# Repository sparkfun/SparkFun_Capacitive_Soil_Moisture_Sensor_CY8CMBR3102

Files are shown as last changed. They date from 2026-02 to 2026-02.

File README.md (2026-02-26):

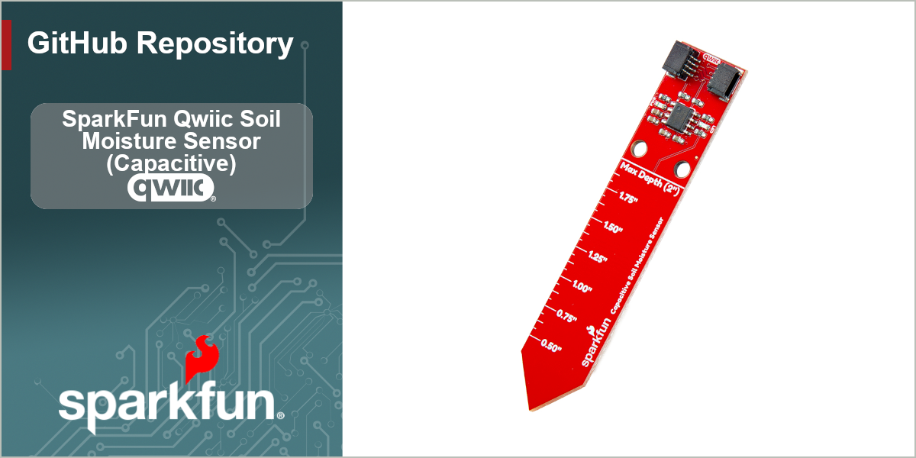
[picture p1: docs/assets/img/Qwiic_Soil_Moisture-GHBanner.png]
SparkFun Qwiic Soil Moisture Sensor (Capacitive) (https://www.sparkfun.com/sparkfun-qwiic-soil-moisture-sensor-capacitive.html)


[*SparkFun Qwiic Soil Moisture Sensor (Capacitive) (SEN-30480)*](https://www.sparkfun.com/sparkfun-qwiic-soil-moisture-sensor-capacitive.html)

The SparkFun Qwiic Soil Moisture Sensor (Capacative) is a simple sensor breakout to measure moisture in soil and similar substances. The breakout measures moisture using a capacitive plate in the board along with the CY8CMBR3102 Capsense<sup>&reg;</sup> Express<sup>&trade;</sup> controller. Because this soil moisture sensor does not have exposed metal leads it's more resistant to corrosion. The board also includes a ruler with both Imperial and Metric units to measure the sensor's depth in soil for more precise moisture data. There's also a blue status LED tied to the CY8CMBR3102 which can be used as a visual indicator for when the sensor measures beyond a user-defined threshold value.

The SparkFun Qwiic Soil Moisture Sensor (Capacative) has code packages available for both the Arduino IDE and MicroPython. These code packages cover how to calibrate the sensor for different soil compositions to get reliable and usable soil moisture data from the sensor.

Repository Contents
-------------------

* **/docs** - GitHub pages documentation files
* **/Documentation** - Datasheets, etc. 
* **/Hardware** - KiCad design files (_pcb, _sch), Schematic (PDF)
* **/Production** - Production panel files (_pcb, gerbers)

Documentation
--------------
* [**Arduino Library**](https://github.com/sparkfun/SparkFun_CY8CMBR3_Arduino_Library) - Arduino library for CY8CMBR3xxx capacitance sensors, specifically for the Qwiic Soil Moisture Sensor (Capacitive).
* [**Python Package**](https://github.com/sparkfun/qwiic_cy8cmbr3_py) - A Python driver for CY8CMBR3xxx capacitance sensors, specifically for the Qwiic Soil Moisture Sensor (Capacitive).
* [**Hookup Guide**](https://docs.sparkfun.com/SparkFun_Capacitive_Soil_Moisture_Sensor_CY8CMBR3102/introduction/) - A basic guide to get started with the Qwiic Soil Moisture Sensor (Capacitive)

Product Versions
-----------------

* [SEN-30480](https://www.sparkfun.com/sparkfun-qwiic-soil-moisture-sensor-capacitive.html) - Initial SparkFun Qwiic Soil Moisture Sensor (Capacitive) release.

License Information
-------------------

This product is _**open source**_! 

Please review the LICENSE.md file for license information. 

If you have any questions or concerns on licensing, please contact technical support on our [SparkFun forums](https://forum.sparkfun.com/viewforum.php?f=152).

Distributed as-is; no warranty is given.

- Your friends at SparkFun.

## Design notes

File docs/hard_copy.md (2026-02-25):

---
icon: material/book-open-variant
---

Need to download or print our hookup guide?

* [Print :fontawesome-solid-print:](../single_page.md) (Single-Page View)
    * To save as a `*.pdf` file, select the **Printer** or **Destination** labeled ++"Save as PDF"++. *(Instructions will vary based on the browser)*

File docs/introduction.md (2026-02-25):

<figure markdown>
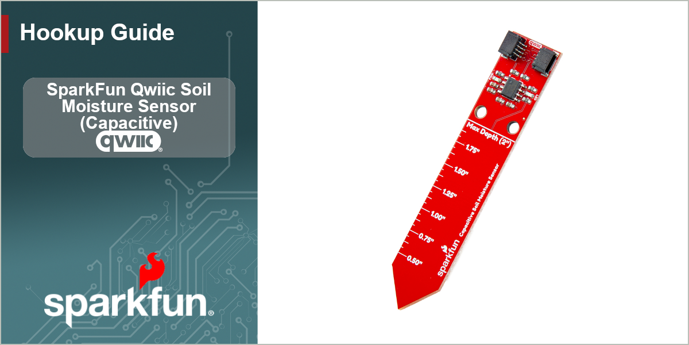
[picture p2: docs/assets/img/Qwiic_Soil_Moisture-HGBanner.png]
Banner Image (https://www.sparkfun.com/sparkfun-qwiic-soil-moisture-sensor-capacitive.html)

</figure>

The SparkFun Qwiic Soil Moisture Sensor (Capacative) is a simple sensor breakout to measure moisture in soil and similar substances. The breakout measures moisture using a capacitive plate in the board along with the CY8CMBR3102 Capsense<sup>&reg;</sup> Express<sup>&trade;</sup> controller. Because this soil moisture sensor does not have exposed metal leads it's more resistant to corrosion. The board also includes a ruler with both Imperial and Metric units to measure the sensor's depth in soil for more precise moisture data. There's also a blue status LED tied to the CY8CMBR3102 which can be used as a visual indicator for when the sensor measures beyond a user-defined threshold value.

The SparkFun Qwiic Soil Moisture Sensor (Capacative) has code packages available for both the Arduino IDE as well as MicroPython. These code packages cover how to calibrate the sensor for different soil compositions to get reliable and usable soil moisture data from the sensor.

In this Quick Start guide we'll cover how to assemble the sensor into a Qwiic circuit and use the SparkFun CY8CMBR3 Arduino Library to get capacitance data we can use to determine soil moisture.

## Required Materials

In order to use this Qwiic breakout board, you'll need the following materials:

* [SparkFun RedBoard IoT - ESP32](https://www.sparkfun.com/sparkfun-iot-redboard-esp32-development-board.html) (or other Arduino development board)
* [Qwiic Cable](https://www.sparkfun.com/flexible-qwiic-cable-100mm.html)

## Resources and Support Documentation

You'll find the board design files (KiCad files & schematic), relevant documentation (datasheets, white papers, etc.) and other helpful links in the **Resources**. Lastly, the **Support** section includes a Troubleshooting page that includes any helpful tips specific to this board as well as information on how to receive technical support from SparkFun.

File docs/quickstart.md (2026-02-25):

In this Quick Start guide we'll assemble the SparkFun Qwiic Soil Moisture Sensor (Capacitive) in a Qwiic circuit with the SparkFun RedBoard - IoT (ESP32) and then demonstrate how to calibrate the sensor and get soil moisture data from it using the SparkFun CY8CMBR3x Arduino Library. This guide assumes users have an understanding of the Qwiic ecosystems and how to use development boards with the Arduino IDE.

<figure markdown>
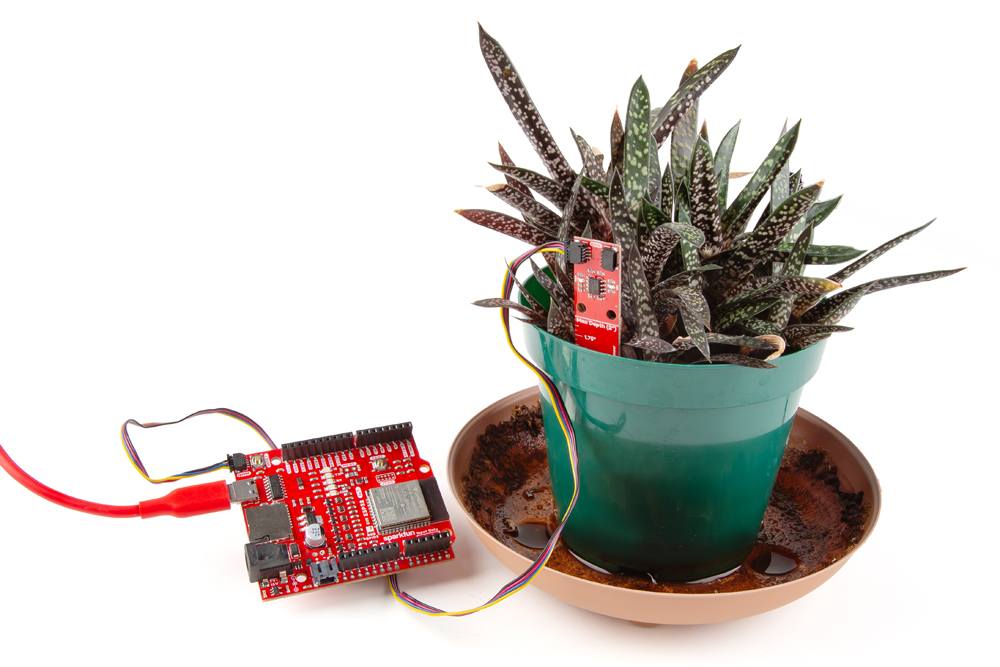
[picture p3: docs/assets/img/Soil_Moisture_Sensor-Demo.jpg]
Qwiic Soil Moisture Sensor demo image

</figure>

## Recommended Reading

If you've never worked with microcontrollers, Arduino (or Python/MicroPython), or the Qwiic ecosystem; take a look at the following resources:

* [SparkFun IoT RedBoard - ESP32 Hookup Guide](https://learn.sparkfun.com/tutorials/iot-redboard-esp32-development-board-hookup-guide)
* [Getting Started with Arduino IDE V2](https://docs.arduino.cc/software/ide-v2/tutorials/getting-started-ide-v2/)
* [Setup and Using MicroPython for Beginners](https://learn.sparkfun.com/tutorials/setup-and-using-micropython-for-beginners)
* [Qwiic Info Page](https://www.sparkfun.com/qwiic?)

## Qwiic Assembly

* Connect the Qwiic Soil Moisture Sensor to the RedBoard IoT using a Qwiic cable.
* Connect the RedBoard IoT to your computer over USB-C.

<figure markdown>
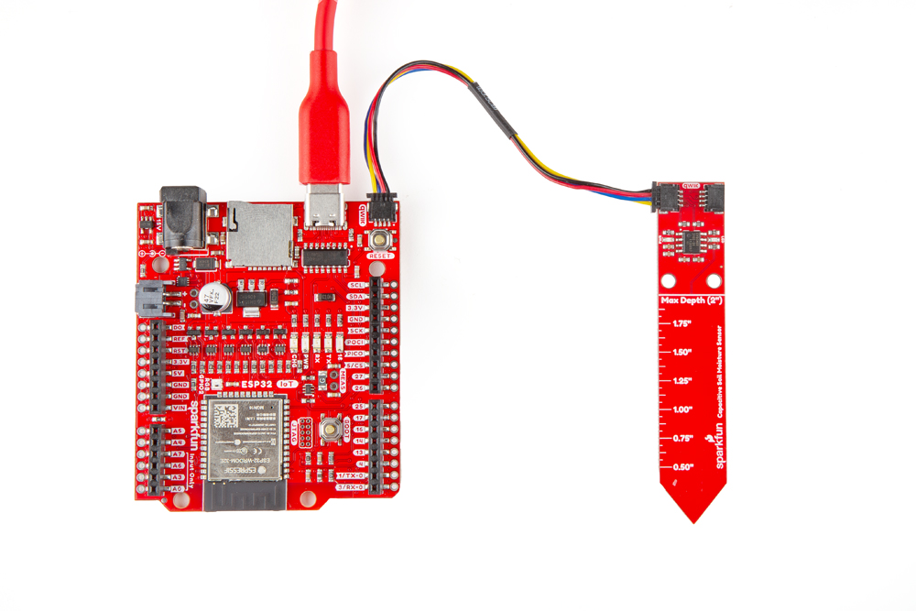
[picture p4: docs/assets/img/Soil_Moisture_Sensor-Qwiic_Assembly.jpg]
Completed Soil Moisture assembly with RedBoard IoT

</figure>

## Soil Moisture Example

Now that we've connected everything up we can move on to uploading example code to get data from the sensor. We'll be demonstrating the basic example included in the Arduino Library but if you're using the MicroPython package the basic example included with it will return the same data shown here. This example initializes the sensor with default settings and prints out the capacitance (in picofarads) returned by the sensor.

* Open the [Arduino IDE](https://docs.arduino.cc/software/ide-v2/tutorials/getting-started-ide-v2/).
* Open the [Library Manager](https://docs.arduino.cc/software/ide-v2/tutorials/ide-v2-installing-a-library/) tool, search for "SparkFun CY8CMBR3" and install the latest version. This library was built using the [SparkFun Toolkit](https://github.com/sparkfun/SparkFun_Toolkit) so if you have not already installed it, search for "SparkFun Toolkit" in the Library Manager to install the dependency. 
* Open **Example01 - Basic Usage**.
* Select your Board (SparkFun RedBoard IoT - ESP32 or other board) and Port and click the "Upload" button.
* After code finishes compiling and uploading, open the [serial monitor](https://docs.arduino.cc/software/ide-v2/tutorials/ide-v2-serial-monitor/) with the baud set to **115200**.

After the code initializes you should see capacitance values (in picofarads/pf) print out every 500ms. Try touching the sensing area or insert it into the soil you'll be measuring to see the values change.

### Sensor Calibration

The Qwiic Soil Moisture Sensor (Capacitive) operates by detecting changes in capacitance in the soil it's inserted into. This works in measuring soil moisture by measuring the soil's change in [relative permittivity (or dielectric constant)](https://en.wikipedia.org/wiki/Relative_permittivity). Put simply, wet soil has a higher relative permittivity than dry soil and therefore the sensor will report higher capacitance values in wet soil. As soil dries out, it loses permittivity and the measured capacitance drops. 

Different soil types and environments can return significantly different capacitance values so it is important to calibrate the Qwiic Soil Moisture Sensor (Capacitive) to get an effective range of values for the soil it's monitoring. Start by inserting the sensor into a *completely dry* soil sample to get the minimum values for the soil. Then place the sensor into a *completely saturated* sample of the same soil to get the max values. With this range defined, you can create thresholds to trigger events like turning on the Soil Moisture Sensor's blue STAT LED when a threshold is exceeded as demonstrated in Example 03 - LED.

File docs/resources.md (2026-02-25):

For more information about the SparkFun Qwiic Soil Moisture Sensor (Capacitive) check out the following resources:

* [Schematic](./assets/board_files/SparkFun_Qwiic_Soil_Moisture_Sensor_Capacitive.pdf)
* [KiCad Files](./assets/board_files/SparkFun_Qwiic_Soil_Moisture_Sensor_Capacitive.zip)
* [Board Dimensions](./assets/board_files/SparkFun_Qwiic_Soil_Moisture_Sensor_Capacitive.jpg)
* [Datasheet](./assets/component_documentation/infineon-cy8cmbr3002-cy8cmbr3102-cy8cmbr3106s-cy8cmbr3108-cy8cmbr3110-cy8cmbr3116-datasheet-en.pdf)
* [SparkFun CY8CMBR3 Arduino Library](https://github.com/sparkfun/SparkFun_CY8CMBR3_Arduino_Library)
* [SparkFun CY8CMBR3 Python Package](https://github.com/sparkfun/qwiic_cy8cmbr3_py)

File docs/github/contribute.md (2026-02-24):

# Contribute: Make an Augmentation!
Spot an improvement opportunity? Feel free to contribute to our open-source design and documentation. 

## :material-file-document-multiple:&nbsp;Improve our Documentation
All of this documentation can be modified by you! Please help us make it better.

* These pages are contained in the [`docs` folder](https://github.com/sparkfun/SparkFun_Capacitive_Soil_Moisture_Sensor_CY8CMBR3102/tree/main/docs) of the [SparkFun Qwiic Soil Moisture Sensor  (Capacitive) repository](https://github.com/sparkfun/SparkFun_Capacitive_Soil_Moisture_Sensor_CY8CMBR3102).

<!-- ### :material-source-pull:&nbsp;Submit a Correction -->
### Submit a Correction

1. With a GitHub account, [fork this repository](https://github.com/sparkfun/SparkFun_Capacitive_Soil_Moisture_Sensor_CY8CMBR3102/fork).
2. Add your corrections or improvements to the markdown file.
3. File a pull request with your changes, and enjoy making the ~~words~~ ~~worlds~~ world a better place.
	* Once received, the documentation specialist will automatically be notified.
	* We will review your suggested improvements to make sure they are correct and fit within our documentation standards.

## :material-cog:&nbsp;Improve our Hardware Design
All of our designs are open-source! Please help us make it better.

* Our board design files are contained in the [`Hardware` folder](https://github.com/sparkfun/SparkFun_Capacitive_Soil_Moisture_Sensor_CY8CMBR3102/tree/main/Hardware) of the [SparkFun Qwiic Soil Moisture Sensor  (Capacitive) repository](https://github.com/sparkfun/SparkFun_Capacitive_Soil_Moisture_Sensor_CY8CMBR3102).

<!-- ### :material-source-pull:&nbsp;Submit a Design Enhancement -->
### Submit a Design Enhancement

1. With a GitHub account, [fork this repository](https://github.com/sparkfun/SparkFun_Capacitive_Soil_Moisture_Sensor_CY8CMBR3102/fork).
2. Add your design augmentation(s)
3. File a pull request with your changes, and enjoy making the ~~words~~ ~~worlds~~ world a better place.
	1. Once received, the engineer in charge of the original design will automatically be notified.
	2. We will review your suggested improvement(s) to verify that they are within our board design standards and meet our product design requirements.
	3. If approved, we will flag these changes for our next board revision. Congrats! 🍻

		!!! info
			Even if your suggestion is accepted, these changes may not be immediately available for purchase. We may have to cycle through our current product inventory first.

## Contributors&nbsp;:clap:
Let's provide some recognition to the contributors for this project!

GitHub Contributors Image
<br>


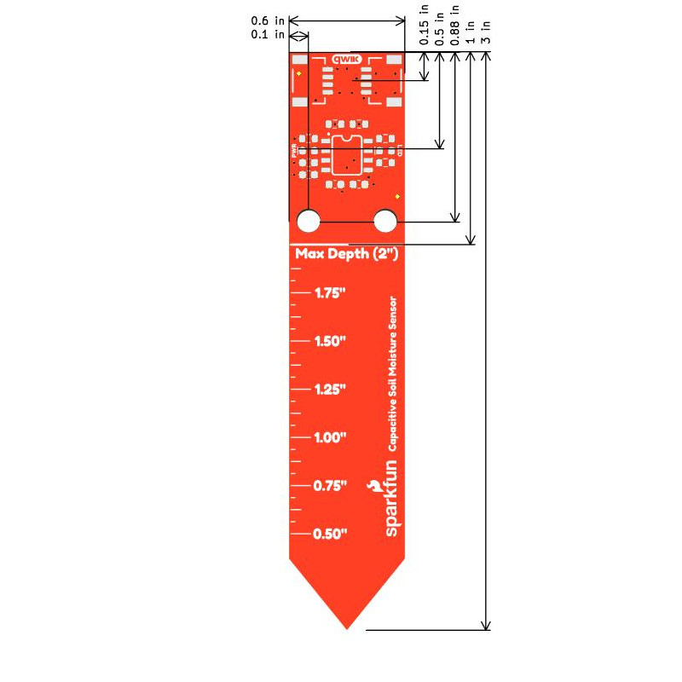
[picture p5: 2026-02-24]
docs/assets/board_files/SparkFun_Qwiic_Soil_Moisture_Sensor_Capacitive.jpg

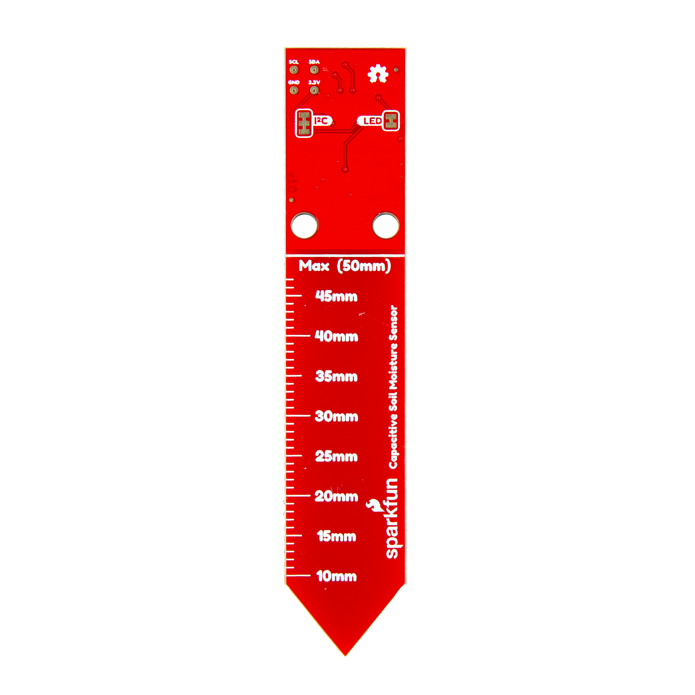
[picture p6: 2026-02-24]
docs/assets/img/Soil_Moisture_Sensor-Back.jpg

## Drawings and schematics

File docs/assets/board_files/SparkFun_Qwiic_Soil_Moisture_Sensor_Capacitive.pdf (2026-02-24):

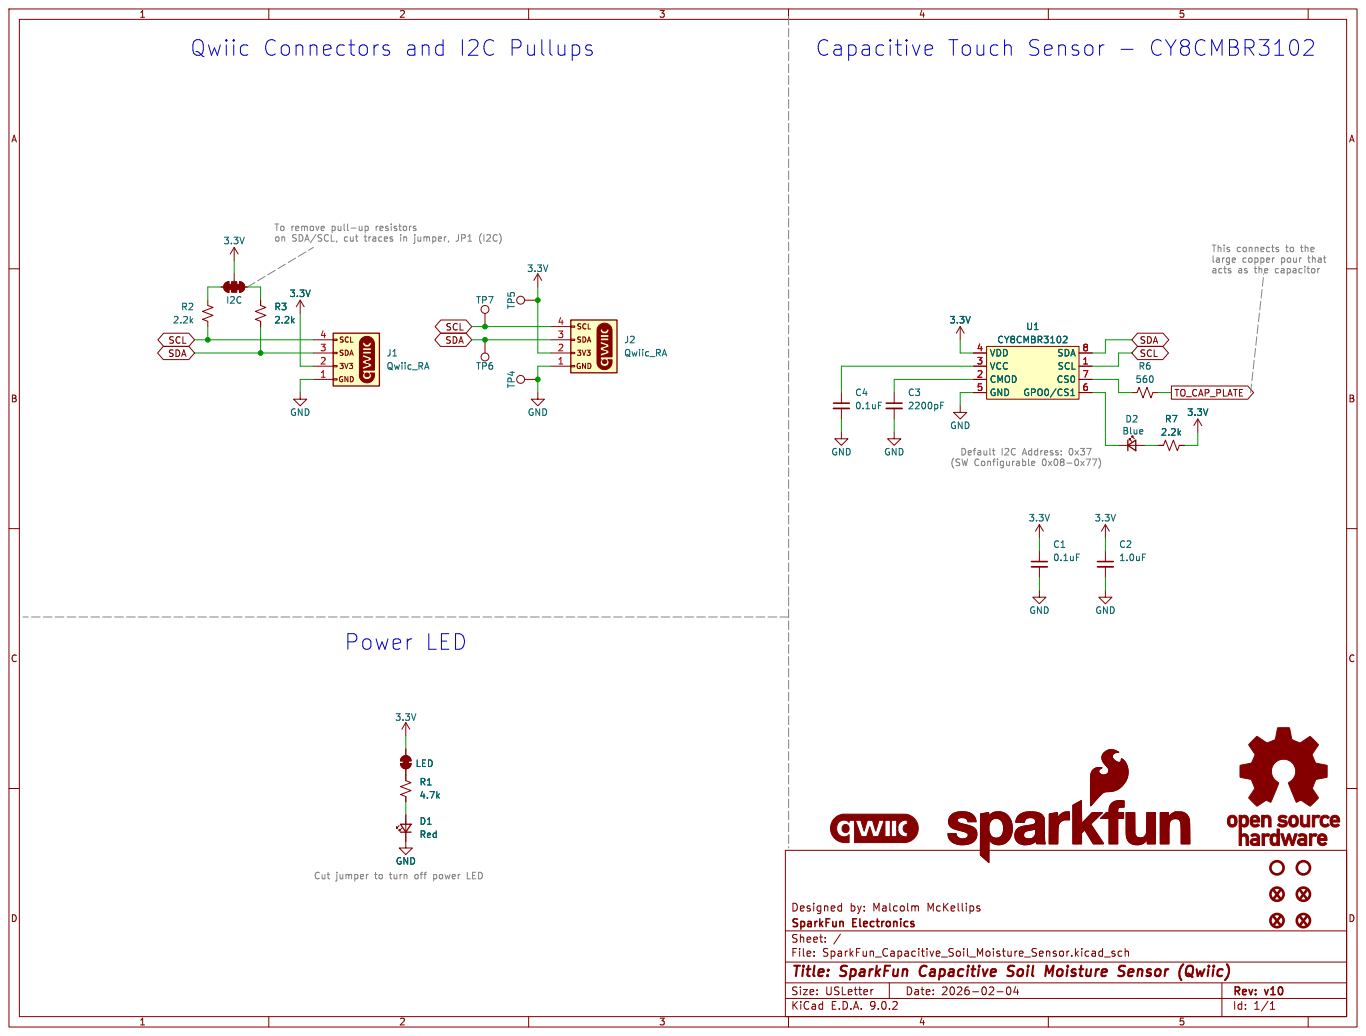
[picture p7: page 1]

large copper pour that acts as the capacitor Default I2C Address: 0x37

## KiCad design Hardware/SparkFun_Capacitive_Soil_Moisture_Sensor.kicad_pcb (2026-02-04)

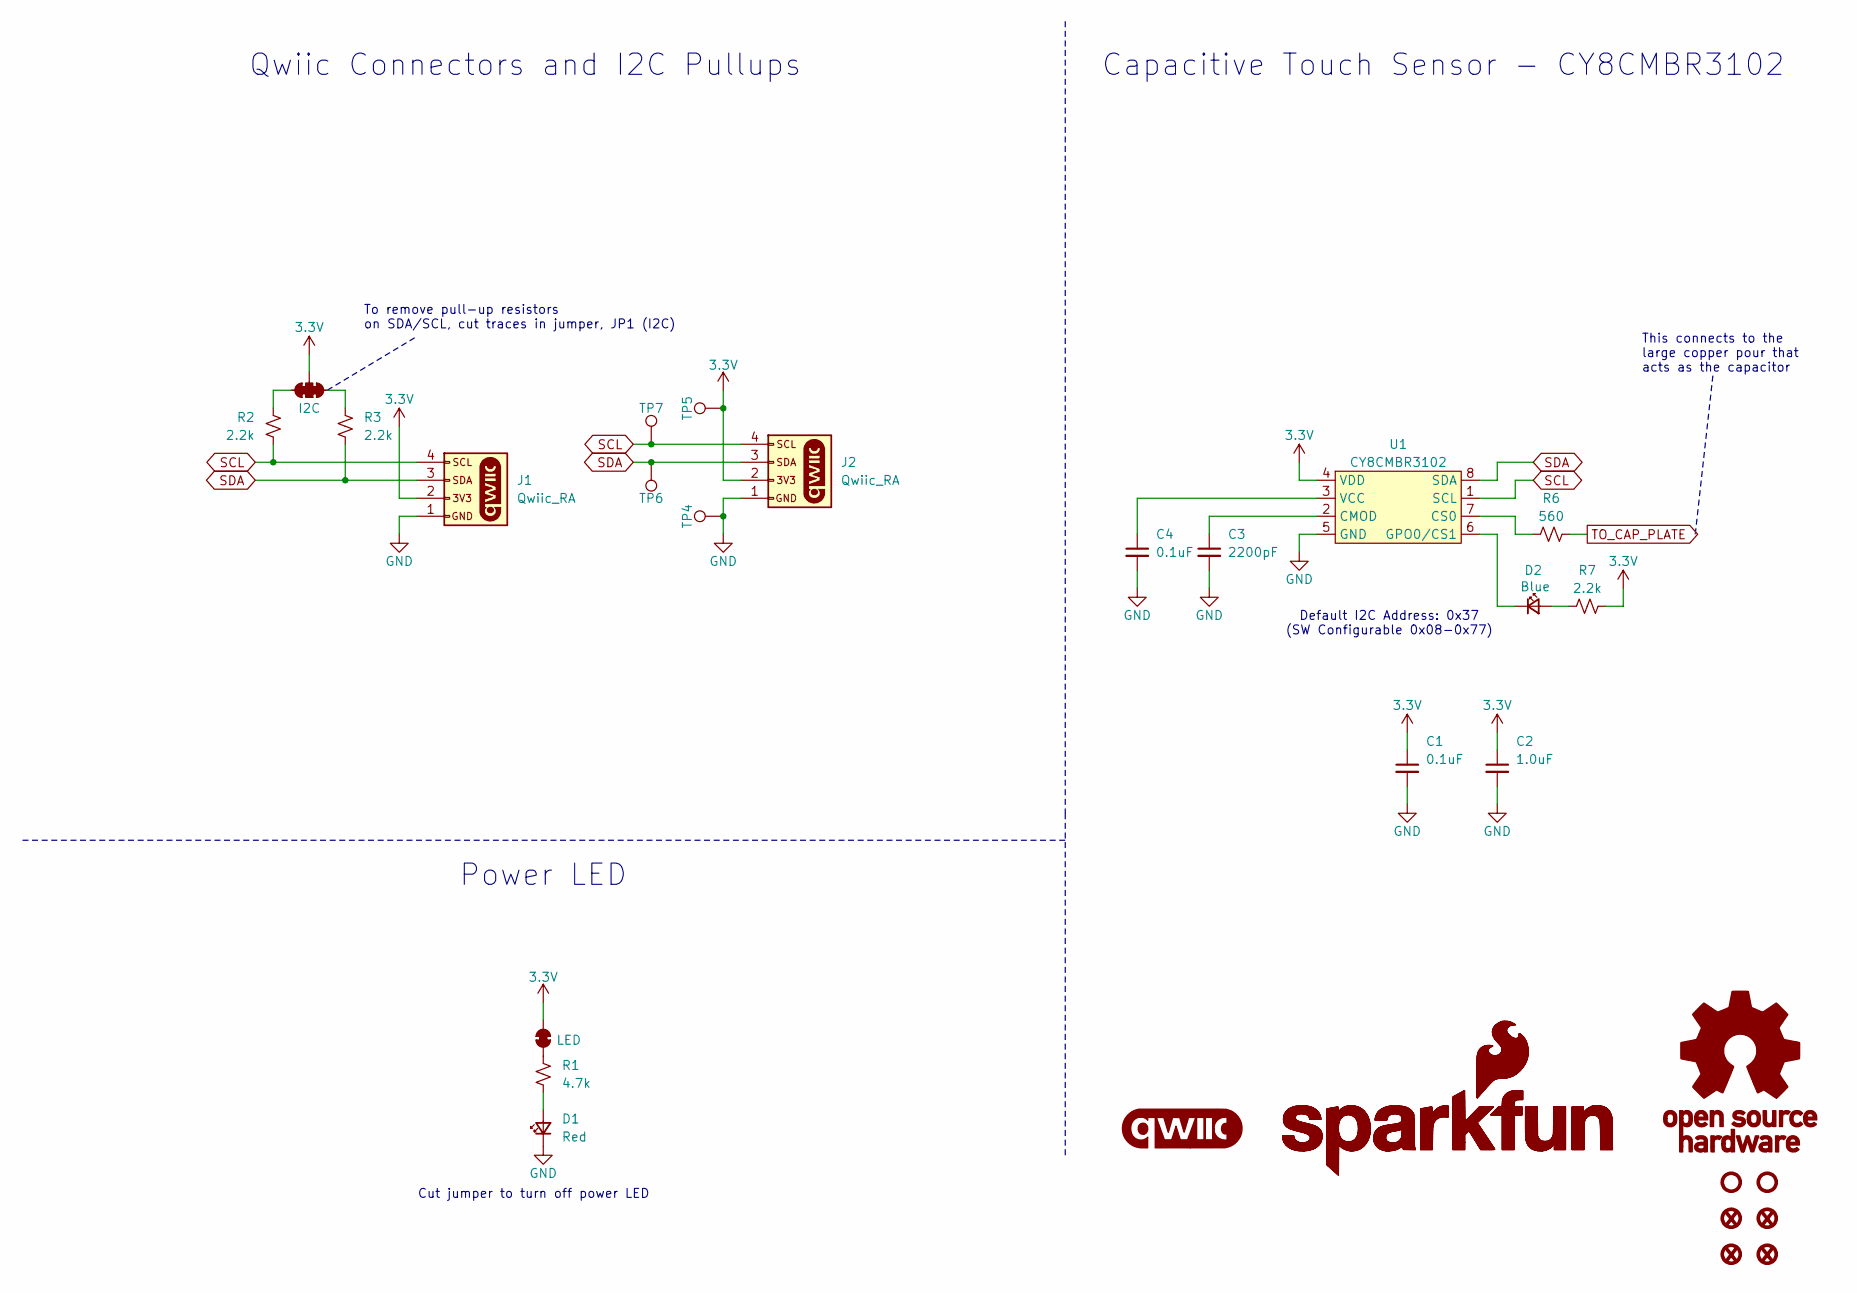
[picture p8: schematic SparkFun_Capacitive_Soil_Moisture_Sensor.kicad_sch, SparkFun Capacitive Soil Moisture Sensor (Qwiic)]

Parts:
C1, C4: 0.1uF; C_0603_1608Metric; Voltage 25V; Tolerance 20%
C2: 1.0uF; C_0603_1608Metric; Voltage 16V; Tolerance 10%
C3: 2200pF; C_0603_1608Metric; Voltage 50V; Tolerance 10%
D1: Red; LED_0603_1608Metric_Red
D2: Blue; LED_0603_1608Metric_Blue
FID1, FID2, FID3, FID4: Fiducial_0.5mm; Fiducial_0.5mm_Mask1mm
G1: SparkFun_Logo; SparkFun_Logo_8mm
G2: SparkFun_Logo
G3: OSHW_Logo; Creative_Commons_License
G4: qwiic_Logo
J1, J2: Qwiic_RA; JST_1x04_P1.0mm_Horizontal_SMD
JP1: LED; Jumper_2_NC_Trace
JP2: I2C; Jumper_3_NC-2_Trace
R1: 4.7k; R_0603_1608Metric
R2, R3, R7: 2.2k; R_0603_1608Metric
R6: 560; R_0603_1608Metric
ST2, ST4: Stand_off; Standoff
TP4, TP5, TP6, TP7: 1.0mm; TestPoint-1.0mm
U1: CY8CMBR3102; SO-8

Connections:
3.3V: C1.1, C2.1, J1.2, J2.2, JP1.2 (B), JP2.2 (B), R7.1, TP5.1, U1.4 (VDD)
GND: C1.2, C2.2, C3.2, C4.2, D1.1 (K), J1.1, J2.1, TP4.1, U1.5 (GND)
unnamed: D1.2 (A), R1.1
unnamed: D2.2 (A), R7.2
unnamed: D2.1 (K), U1.6 (GPO0/CS1)
unnamed: JP1.1 (A), R1.2
unnamed: JP2.1 (A), R3.1
unnamed: JP2.3 (C), R2.1
unnamed: C3.1, U1.2 (CMOD)
unnamed: R6.1, U1.7 (CS0)
unnamed: C4.1, U1.3 (VCC)
SCL: J1.4, J2.4, R2.2, TP7.1, U1.1 (SCL)
SDA: J1.3, J2.3, R3.2, TP6.1, U1.8 (SDA)
TO_CAP_PLATE: R6.2

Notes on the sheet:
Qwiic Connectors and I2C Pullups
Capacitive Touch Sensor - CY8CMBR3102
Cut jumper to turn off power LED
To remove pull-up resistors on SDA/SCL, cut traces in jumper, JP1 (I2C)
This connects to the large copper pour that acts as the capacitor
Power LED
Default I2C Address: 0x37 (SW Configurable 0x08-0x77)

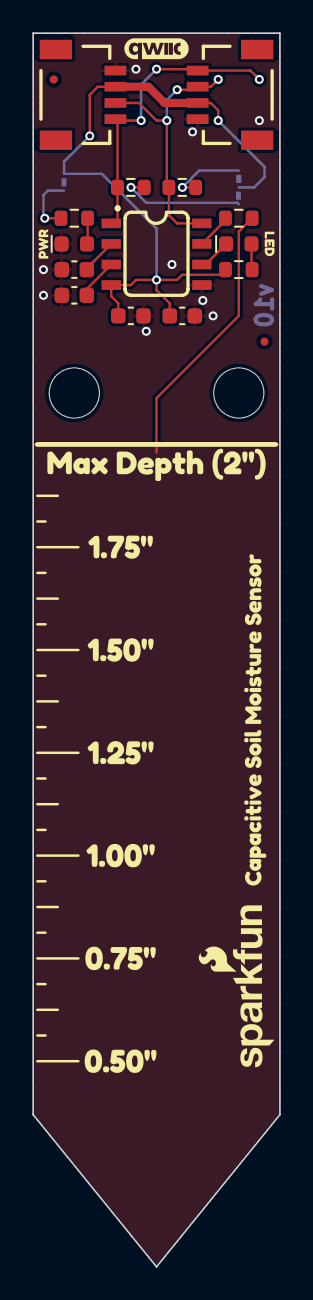
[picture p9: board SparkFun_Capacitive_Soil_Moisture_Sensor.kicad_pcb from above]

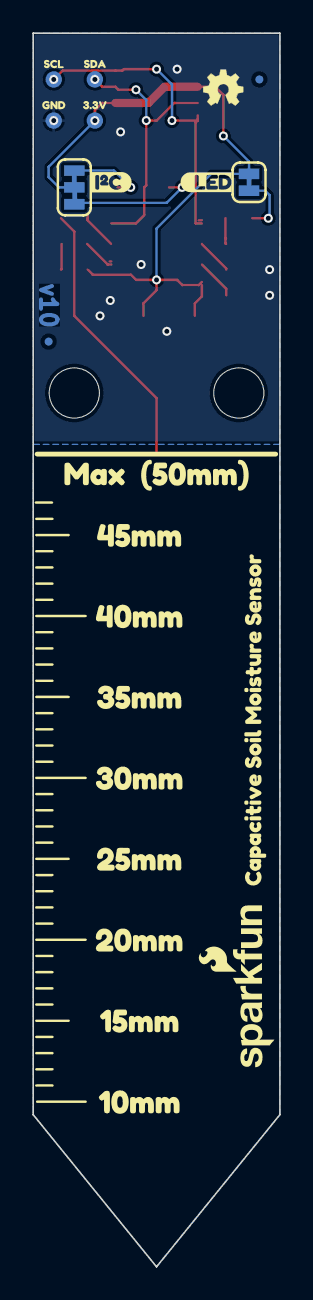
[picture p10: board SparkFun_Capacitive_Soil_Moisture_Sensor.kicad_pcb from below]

Board: 2 copper layers, 15.2 x 76.2 mm, 54 parts (25 on the bottom side), 13 nets.

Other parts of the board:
Ref**: Val**; OSHW_Logo_2.5mm
kibuzzard-693B565E, kibuzzard-693B565E#2: G***; kibuzzard-693B565E
kibuzzard-693C8DDA: G***; kibuzzard-693C8DDA
kibuzzard-693C8DE4: G***; kibuzzard-693C8DE4
kibuzzard-69334C1A: G***; kibuzzard-69334C1A
kibuzzard-69837BBB: G***; kibuzzard-69837BBB
kibuzzard-69837BD1: G***; kibuzzard-69837BD1
kibuzzard-69837BDA: G***; kibuzzard-69837BDA
kibuzzard-69837BE0: G***; kibuzzard-69837BE0
kibuzzard-69837BE5: G***; kibuzzard-69837BE5
kibuzzard-69837BE9: G***; kibuzzard-69837BE9
kibuzzard-69837BEE: G***; kibuzzard-69837BEE
kibuzzard-69837BF5: G***; kibuzzard-69837BF5
kibuzzard-693350BE: G***; kibuzzard-693350BE
kibuzzard-696937A1: G***; kibuzzard-696937A1
kibuzzard-696937A5: G***; kibuzzard-696937A5
kibuzzard-6937166E: G***; kibuzzard-6937166E
kibuzzard-6937167A: G***; kibuzzard-6937167A
kibuzzard-6969377A: G***; kibuzzard-6969377A
kibuzzard-6969378A: G***; kibuzzard-6969378A
kibuzzard-6969379D: G***; kibuzzard-6969379D
kibuzzard-6983799B: G***; kibuzzard-6983799B
kibuzzard-69371667: G***; kibuzzard-69371667
kibuzzard-69371675: G***; kibuzzard-69371675
kibuzzard-69693792: G***; kibuzzard-69693792
kibuzzard-69693797: G***; kibuzzard-69693797

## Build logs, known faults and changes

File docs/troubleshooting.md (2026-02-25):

## Sensor Calibration

The Qwiic Soil Moisture Sensor (Capacitive) operates by detecting changes in capacitance in the soil it's inserted into. This works in measuring soil moisture by measuring the soil's change in [relative permittivity (or dielectric constant)](https://en.wikipedia.org/wiki/Relative_permittivity). Put simply, wet soil has a higher relative permittivity than dry soil and therefore the sensor will report higher capacitance values in wet soil. As soil dries out, it loses permittivity and the measured capacitance drops. 

Different soil types and environments can return significantly different capacitance values so it is important to calibrate the Qwiic Soil Moisture Sensor (Capacitive) to get an effective range of capacitance values for the soil it's monitoring. Start by inserting the sensor into a *completely dry* soil sample to get the minimum values for the soil. Then place the sensor into a *completely saturated* sample of the same soil to get the max values. With this range defined, you can create thresholds to trigger events like turning on the Soil Moisture Sensor's blue STAT LED when a threshold is exceeded as demonstrated in Example 03 - LED.

## General Troubleshooting

!!! note
    <span class="glyphicon glyphicon-question-sign" aria-hidden="true"></span>
        <strong> Not working as expected and need help? </strong> <br /><br />

    If you need technical assistance and more information on a product that is not working as you expected, we recommend heading on over to the <a href="https://www.sparkfun.com/technical_assistance">SparkFun Technical Assistance</a> page for some initial troubleshooting. <br /><br />

    <div style="text-align: center"><a href="https://www.sparkfun.com/technical_assistance" target="sfe_technical_assistance" class="md-button">SparkFun Technical Assistance Page</a></div>

    If you don't find what you need there, the <a href="https://community.sparkfun.com/">SparkFun Forums</a> are a great place to find and ask for help. If this is your first visit, you'll need to create a forum account to search product forums and post questions.<br /><br />

    <div style="text-align: center"><a href="https://community.sparkfun.com/" class="md-button md-button--primary">Log Into SparkFun Forums</a></div>

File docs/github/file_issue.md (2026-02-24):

# Did we make a mistake?

Spot something wrong? Please let us know. 

## Discrepancies in the Documentation

All of our documentation can be modified by you! Please help us make it better.

* The documentation files for these pages are contained in the [`docs` folder](https://github.com/sparkfun/SparkFun_Capacitive_Soil_Moisture_Sensor_CY8CMBR3102/tree/main/docs) of the [SparkFun Qwiic Soil Moisture Sensor  (Capacitive) repository](https://github.com/sparkfun/SparkFun_Capacitive_Soil_Moisture_Sensor_CY8CMBR3102).

### 🔍 Spot something wrong?

If a section of the documentation is incorrect, please [open an issue](https://github.com/sparkfun/SparkFun_Capacitive_Soil_Moisture_Sensor_CY8CMBR3102/issues) and let us know.

### Do you have a suggested correction?

1. With a GitHub account, [fork this repository](https://github.com/sparkfun/SparkFun_Capacitive_Soil_Moisture_Sensor_CY8CMBR3102/fork).
2. Add your correction(s) or improvement(s) to the markdown file(s)
3. File a pull request with your changes, and enjoy making the ~~words~~ ~~worlds~~ world a better place.
	* Once received, the documentation specialist will automatically be notified.
	* We will review your suggested improvement(s) to make sure they are correct and fit within our documentation standards.

## Problems in the Hardware Design

All of our designs are open-source! Please help us make it better.

* Our board design files are contained in the [`Hardware` folder](https://github.com/sparkfun/SparkFun_Capacitive_Soil_Moisture_Sensor_CY8CMBR3102/tree/main/Hardware) of the [SparkFun Qwiic Soil Moisture Sensor  (Capacitive) repository](https://github.com/sparkfun/SparkFun_Capacitive_Soil_Moisture_Sensor_CY8CMBR3102).

### Does something not make sense? 🤔

If part of the design is confusing, please [open an issue](https://github.com/sparkfun/SparkFun_Capacitive_Soil_Moisture_Sensor_CY8CMBR3102/issues) and let us know.

### Did we forget to include an important function of the board? 🤦

If part of the board's functionality is missing, please [open an issue](https://github.com/sparkfun/SparkFun_Capacitive_Soil_Moisture_Sensor_CY8CMBR3102/issues) and file a feature request.

!!! tip "Design Considerations"
	Please keep in mind that we may intentionally exclude certain functions of the board to meet our product design requirements.
	
	* *For example, our Qwiic Micro boards are intended to fit on a small board layout and only use I<sup>2</sup>C communication; therefore, we may not have the SPI and interrupt pins available for users.*

### Do you wish to contribute directly to improving the board design?

1. With a GitHub account, [fork this repository](https://github.com/sparkfun/SparkFun_Capacitive_Soil_Moisture_Sensor_CY8CMBR3102/fork).
2. Add your design augmentation(s)
3. File a pull request with your changes, and enjoy making the ~~words~~ ~~worlds~~ world a better place.
	1. Once received, the engineer in charge of the original design will automatically be notified.
	2. We will review your suggested improvement(s) to verify that they are within our board design standards and meet our product design requirements.
	3. If approved, we will flag these changes for our next board revision. Congrats! 🍻

		!!! info
			Even if your suggestion is accepted, these changes may not be immediately available for purchase. We may have to cycle through our current product inventory first.

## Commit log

2025-12-05 Add initial schematic and layout
    [SparkFun_Capacitive_Soil_Moisture_Sensor.kicad_pcb, SparkFun_Capacitive_Soil_Moisture_Sensor.kicad_sch]
2025-12-08 Cleanup test points and silkscreen, remove acid traps
    [SparkFun_Capacitive_Soil_Moisture_Sensor.kicad_pcb, SparkFun_Capacitive_Soil_Moisture_Sensor.kicad_sch]
2025-12-09 Make schematic updates from preliminary review
    [SparkFun_Capacitive_Soil_Moisture_Sensor.kicad_sch]
2025-12-11 Add functional changes to PCB from review.
    Achieves MVP, does not have all requested aesthetic changes.
    [SparkFun_Capacitive_Soil_Moisture_Sensor.kicad_pcb]
2025-12-11 Update schematic with new cap sensing chip
    [SparkFun_Capacitive_Soil_Moisture_Sensor.kicad_sch]
2025-12-11 Add ruler to silkscreen on PCB
    [SparkFun_Capacitive_Soil_Moisture_Sensor.kicad_pcb]
2025-12-12 Add schematic fixes from initial review
    [SparkFun_Capacitive_Soil_Moisture_Sensor.kicad_sch]
2025-12-12 Update PCB with new CY8CMBR3 IC
    [SparkFun_Capacitive_Soil_Moisture_Sensor.kicad_pcb, SparkFun_Capacitive_Soil_Moisture_Sensor.kicad_sch]
2025-12-15 Cleanup symmetry and add measurements
    [SparkFun_Capacitive_Soil_Moisture_Sensor.kicad_pcb]
2025-12-17 Fix sizing and naming in schematic based on review
    [SparkFun_Capacitive_Soil_Moisture_Sensor.kicad_sch]
2025-12-17 Add PCB fixes from review
    [SparkFun_Capacitive_Soil_Moisture_Sensor.kicad_pcb, SparkFun_Capacitive_Soil_Moisture_Sensor.kicad_sch]
2025-12-18 Create version of the PCB with components alligned to 12.5mil grid
    [SparkFun_Capacitive_Soil_Moisture_Sensor.kicad_pcb]
2025-12-19 Update cap to correct prod_id
    [SparkFun_Capacitive_Soil_Moisture_Sensor.kicad_pcb, SparkFun_Capacitive_Soil_Moisture_Sensor.kicad_sch]
2026-01-15 Roll version for reds and increase silk font
    [SparkFun_Capacitive_Soil_Moisture_Sensor.kicad_pcb, SparkFun_Capacitive_Soil_Moisture_Sensor.kicad_sch]
2026-01-16 Adds Gerbers - waiting on parts
    [SparkFun_Capacitive_Soil_Moisture_Sensor.GBL, SparkFun_Capacitive_Soil_Moisture_Sensor.GBO, SparkFun_Capacitive_Soil_Moisture_Sensor.GBP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]
2026-01-22 Remove the 330 ohm series I2C resistors.
    These resistors cause issues when you daisy chain qwiic devices as they
    form a voltage divider with the pull-up resistance.
    [SparkFun_Capacitive_Soil_Moisture_Sensor.kicad_pcb, SparkFun_Capacitive_Soil_Moisture_Sensor.kicad_sch]
2026-02-04 Add changes from final review
    [SparkFun_Capacitive_Soil_Moisture_Sensor.kicad_pcb, SparkFun_Capacitive_Soil_Moisture_Sensor.kicad_sch]
2026-02-04 Add metric ruler
    [SparkFun_Capacitive_Soil_Moisture_Sensor.kicad_pcb]
2026-02-04 Center max line
    [SparkFun_Capacitive_Soil_Moisture_Sensor.kicad_pcb]

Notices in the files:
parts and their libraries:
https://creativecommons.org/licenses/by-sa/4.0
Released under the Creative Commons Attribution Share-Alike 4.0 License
